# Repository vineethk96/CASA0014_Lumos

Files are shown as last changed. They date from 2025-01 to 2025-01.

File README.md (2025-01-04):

# CASA0014_Lumos

<p align="center">
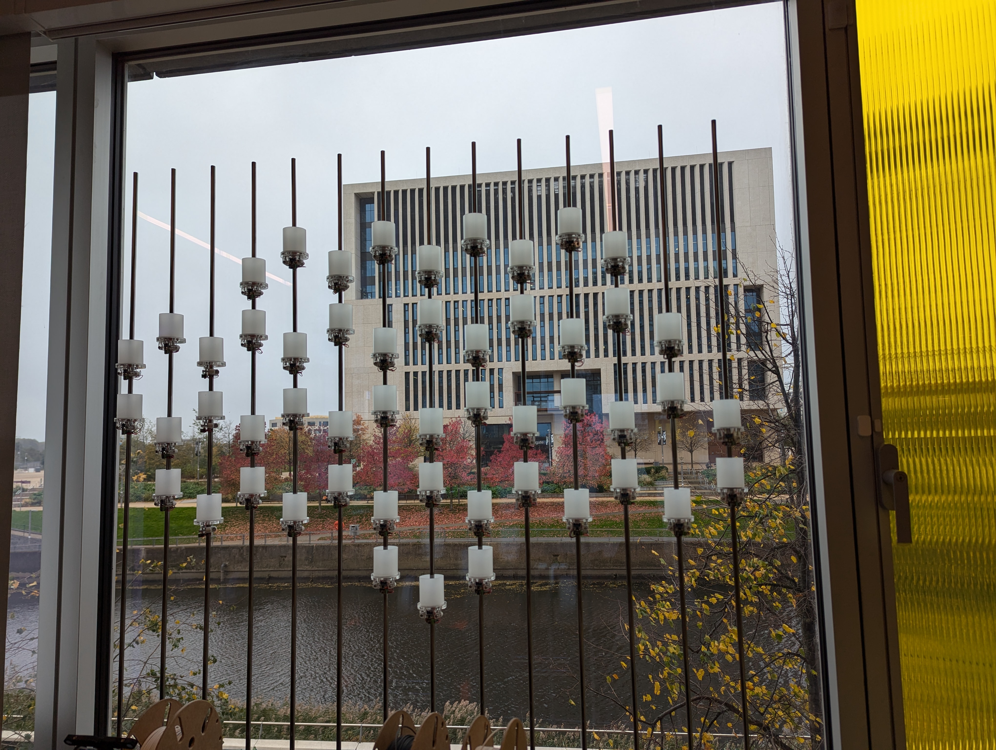
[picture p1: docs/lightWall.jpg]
    
</p>

### Description

Lumos is an User Interface that allows individuals to control individual lights on the Light Wall.

The Light Wall works by using an MQTT Server that listens to incoming messages to the Topic `mqtt.cetools.org/student/CASA0014/light/`
These messages can identify which LED Node to select by adding the corresponding number to the topic, as well as exactly which pixel to illuminate and it's color within the message body as so:

```
{
"pixelid": ledNode,
"R": red_byte,
"G": green_byte,
"B": blue_byte,
"W": white_byte
}
```

To interact with the Light Wall, Lumos uses a collection of 3 TLV493D Magnetometers to read the distance a magnet is from them to create a light value between 0 and 255. Each of the 3 magnetometers are designated Red, Green, and Blue, and the magnet itself is held within the wand.
Users can also select a specific LED Node to light up using the dial to the left of the ring.

## Features

- LED Node Selection via Dial
- Color Changeability via Ring and Wand

## Contents

- Hardware Used
  - Areas for Improvement
- Software Overview
  - Installation and Running
  - Architecture
  - Algorithms
  - Areas for Improvement
- Inspiration and Helpful Links

## Hardware

- Arduino MKR WIFI 1010 (Microcontroller)
- TLV493D (Magnetometer)
- TCA9548A (I2C Multiplexer)
- PEC11 (Rotary Encoder)
- SSD1306 (OLED Display)

### Areas for Improvement

The major area for improvement is with the TLV493D magnetometers. They are not strong enough to detect a proper magnetic disturbance outside of 3-4cm away.

## Software

### Installation and Running

This project was developed using the PlatformIO extension on Visual Studio Code. To start with users must install both items, which can be found at the below links:

- [Visual Studio Code](https://code.visualstudio.com/download)
- [PlatformIO IDE](https://platformio.org/platformio-ide)

Additionally, the following libraries must be installed:

```
	arduino-libraries/WiFiNINA@^1.8.14
	adafruit/Adafruit NeoPixel@^1.12.3
	adafruit/Adafruit GFX Library@^1.11.11
	adafruit/Adafruit SSD1306@^2.5.13
	adafruit/Adafruit BusIO@^1.16.2
	paulstoffregen/Encoder@^1.4.4
	bblanchon/ArduinoJson@^7.2.0
	knolleary/PubSubClient@^2.8
	infineon/TLV493D-Magnetic-Sensor@^1.0.4
	wifwaf/TCA9548A@^1.1.3
```

Once the above applications, extensions, and libraries have been installed, the application can be run by clicking the Arrow button at the bottom of the screen, and opening the Serial Monitor with the Plug.

#### Quick PlatformIO Info:

##### Install Libraries

Once PlatformIO is installed, an alien head should pop up on the left toolbar
PlatformIO_Logo

Click the head, and on the left bar there will be a `Quick Access` table, and under `PIO Home` there will be a `Libraries` entry.
From here, you can install all the libraries.

##### Build and Running Applications

At the bottom toolbar you will see a couple new items.

- The Checkmark will build your code.
- The Arrow will upload your code to the microcontroller
- The Plug will open the Serial Terminal

### Architecture

#### Hardware

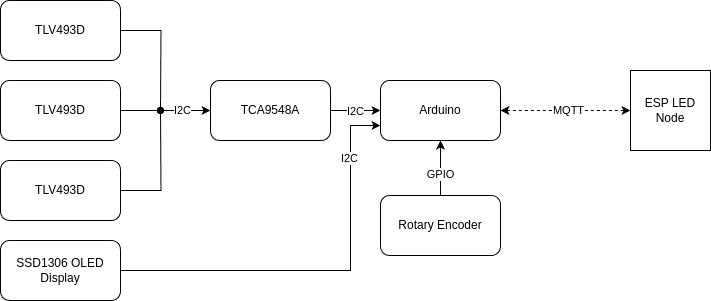
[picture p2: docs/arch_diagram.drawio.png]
Basic Circuit


#### Software

At a high-level everything is broken down by it's physical functionality. The project itself is comprised of 2 parts: the dial, and the ring. As such, the `EncoderKnob` library contains everything to communicate with the components of the ring, those being the PEC11 Rotary Encoder, and the SSD1306 OLED Display. Equally the ring is simply the readings from the 3 magnetometers, and the mapping.

### Algorithms

Two simple algorithms were build for this application. One for rotating between I2C Channels on the Mux, and the other for cleaning up the incoming readings from the magnetometers to get a more meaningful and accurate representation of the data.

#### I2C Switching

The TCA9548A multiplexer works by allowing the user access to 1 of it's 8 possible I2C channels at a single time. Therefore, when interfacing with multiple components with the same I2C Address, I designed a simple, but effective method to switch between channels, while also saving memory. This works by making a single generic magnetometer object, and using a enumerated value to iterate between the channels.

#### Input Data Cleanup

As a result of using this magnetometer for the project, the recorded strength of the magnet significantly dropped off when about 5 to 6 cm away. This paired with the speed and switching of device readings, led to very inconsistent readings which didn't make a lot of sense to what the users would percieve. To solve this, I applied a rolling average algorithm, along with a different mapping to adjust the values. The current issue with this, is since the values are so low at around 5 to 6 cm away, the color saturation really just transitions from on to off, without much of a gradient betwen them. This can be cleaned up with a magnetometer with a larger field of reading, or even more powerful magnets.

### Areas for Improvement

The primary area would be to clean up the input mappings, also selecting magnetometers with an adjustable I2C address would remove the need for the mux, and simplify the code, while providing faster readings.
Also, there was an attempt at creating a library to quickly create and send the MQTT messages, however after testing, using the MQTT message to change the whole light at once added too much extra complexity for an inconsistent output.

## Inspiration and Helpful Links

- https://www.instructables.com/OLED-I2C-DISPLAY-WITH-ARDUINO-Tutorial/
- https://www.instructables.com/Arduino-and-the-SSD1306-OLED-I2C-128x64-Display/
- https://github.com/scottbez1/smartknob/tree/master/cad
- https://www.instructables.com/Hackable-Rotary-Control-With-Built-in-Display-a-Te/
- https://www.thingiverse.com/thing:2641409

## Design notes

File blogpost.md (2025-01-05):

# Project Lumos

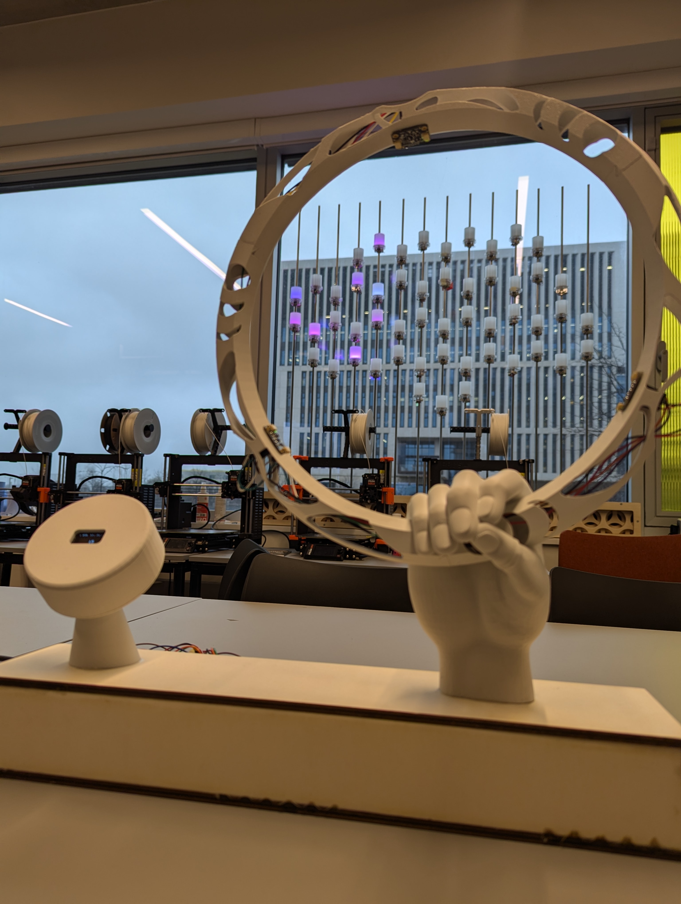
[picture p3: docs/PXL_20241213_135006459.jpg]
Lumos


In the age of connected systems, user interfaces are getting increasingly boring and digitized. Monocolor apps with color wheels have taken away from the tactile buttons and knobs of the past. This project seeks to break those patterns, and bring back the fun in interacting with smart tech.

There is a word that this project is built around. One that my professor had mentioned early in the term. We were talking about how ubiquitous systems are built, how we use various wireless technologies to interact with our environment in a way that people never notice. He said that it all works like "Magic", and that stuck.

You can't go anywhere now without experiencing the magic; from resturant pagers, to smart HVAC systems, there are invisible data streams everywhere. To most developers, we use various apps and dashboards to visualize and analyze the streams. Within our homes, we have smart assistants like Google Home or Amazon Alexa to flip lights. If we want more detailed control, we have to open the app, and go through various menus to get to the exact items we want to change. Suddenly the magic is broken. The blinding blue light from the screen, the tapping through menus, swiping through colors, suddenly the manual labor of a switch flip has spiraled out of control.

This projects begins with a simple idea, chuck out the blue screen of death. Bring back the feel of the analog, and ubiqitous-ness of smart tech. The kinda stuff that makes you go "Wow that's like magic"

Swish&Flick

Much like the magic in the Harry Potter franchise, this project seeks to bring back that joy.

## The Boy Who Lived (Introduction)

< Describe some background of the project >

## The Sorting Hat (Conceptualization)

As Mark Twain once said: "There is no such thing as an original idea". As such, I started off by looking at our professors device:

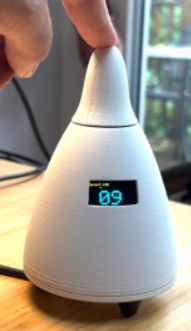
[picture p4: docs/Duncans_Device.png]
Professor Duncan's device

_Professor Duncan's implementation._

In the above image, the knob at the top selects the LED Node, and by clicking the knob, a static command is sent over MQTT to the Light wall.

I began by looking at methods to expand on the functionality of this. Add color and brightness selection to the LED Node selector. One idea was a multi-stage knob. Using multiple encoders at different levels almost like a combination lock.

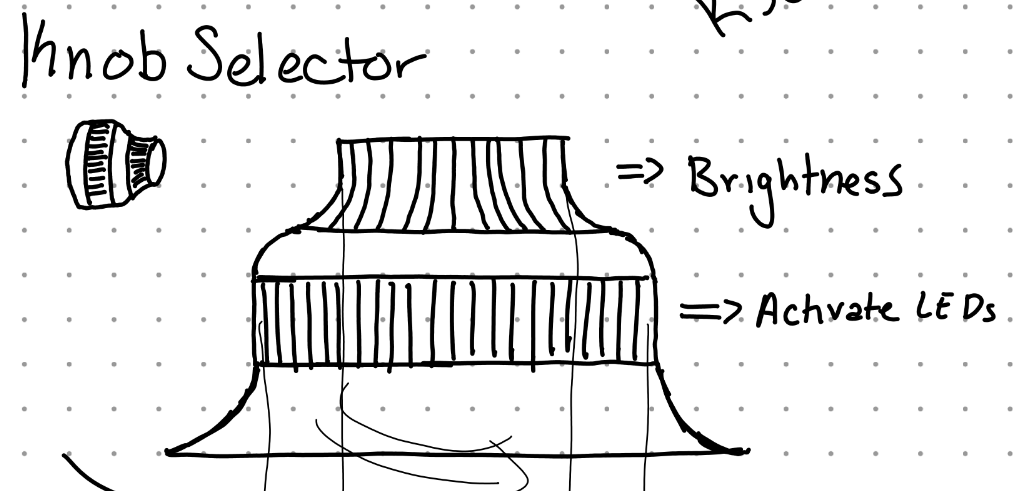
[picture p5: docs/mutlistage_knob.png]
Multistage Knob

_Multi-stage Knob_

Internally the 2 stages would be ring gears, with a unique rotary encoder as the planetary gear to adjust specific settings. However, each additional stage added an exponential increase to the physical complexity to the device. Another idea was to put a embed a touch screen to the knob face with a gradiant selector.

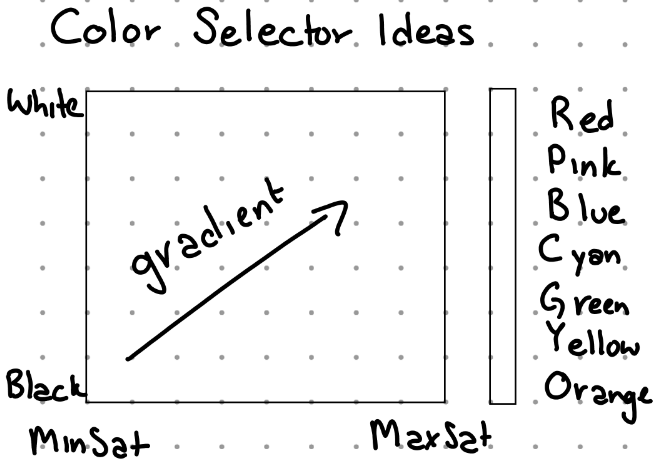
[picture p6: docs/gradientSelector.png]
Gradient Selector

_Gradient Selector_

As you might've caught on, that idea was shot down very quickly. **No touchscreens here!**

In a desperate attempt to make something unique, I began scouring the Adafruit website's sensor section looking for neat sensors I could work with. I figured finding a unique sensor would give me the niche factor I was looking for. Microphones, Strain sensors, ultrasonic, Color sensors, or gyroscopes were considered, and quickly tossed aside. Finally I came across some magnetometers, and an idea started to form.

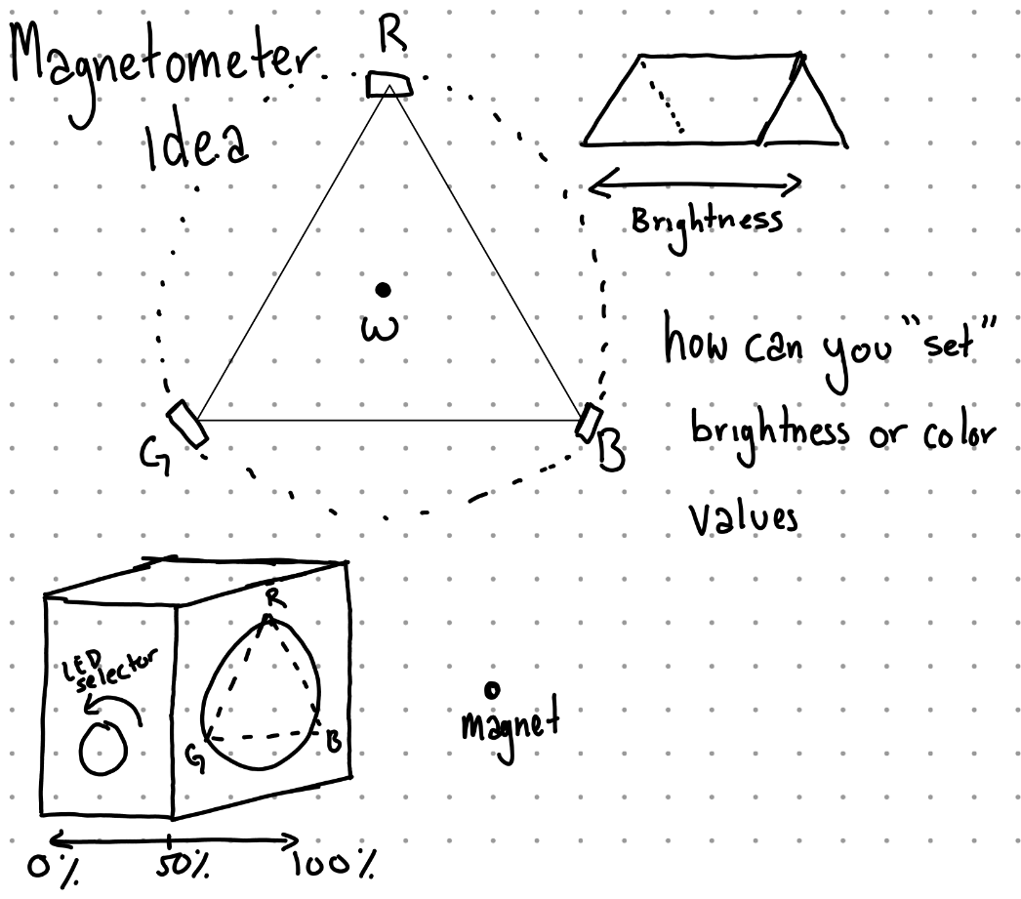
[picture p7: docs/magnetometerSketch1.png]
Magnetometer Sketches

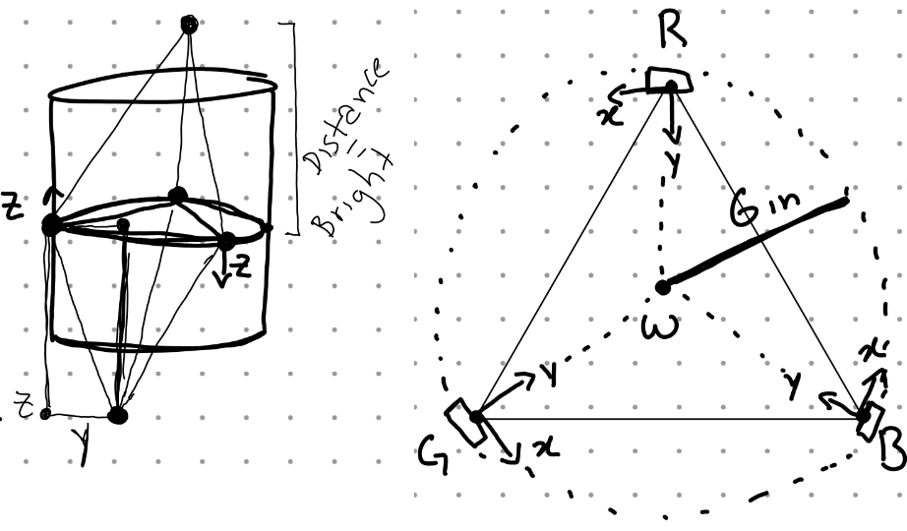
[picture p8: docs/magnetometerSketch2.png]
Magnetometer Sketches

_Magnetometer sketches and functional mapping_

By arranging 3 magnetometers in a triangle, I could wave a magnet between them, and get a whole gradient of colors. On top of that, the sensors could also measure the magnetic field in the X, Y, and Z coordinates, meaning this could be further enhanced by moving the magnet closer and further to the sensors to adjust the brightness. With the magnetometer selected, and an initial concept mapped out, I needed to figure out how all these ideas were going to come together. It wasn't enough to just change the color of a single LED Node, but I had to also select the specific node. Leaning on the knob concept from Duncan, I decided to incorporate both into a single design.

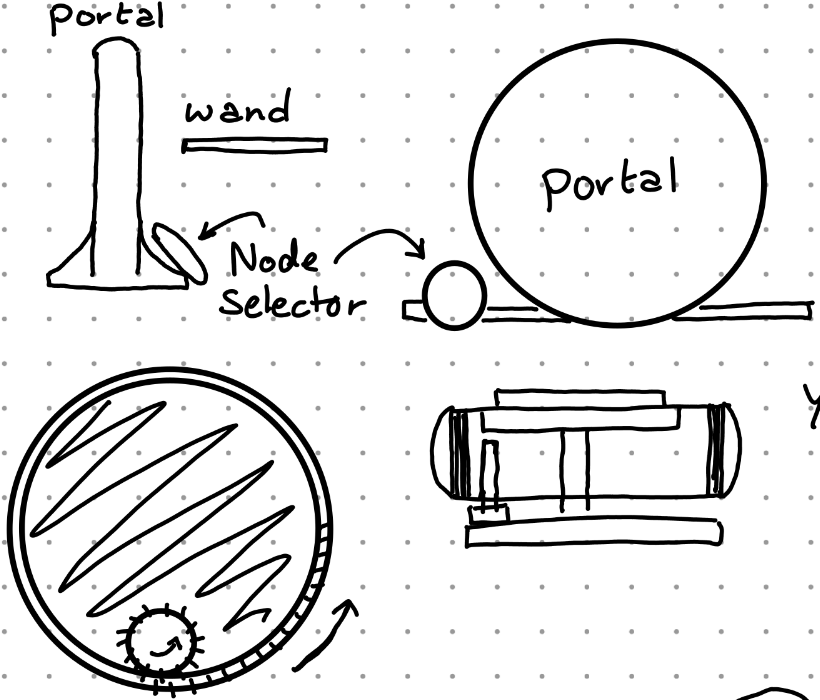
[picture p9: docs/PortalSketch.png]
Initial Portal Sketches

_Initial Project Sketches_

The final descision was to implement both. A knob which could select a LED Node, and a ring (described as the Portal) which holds the magnetometer array to adjust colors.

## Diagon Alley (Collecting Components)

< Purchasing items >
Breaking down the systems.
There are 2 systems, the Ring and the Knob

## The Journey from Platform Nine and Three-Quarters (Modeling and Assembly)

< Modeling and Assembly >

## Through the Trapdoor (Software and Algorithms)

< Software and Algo Overview >

## The Mirror of Erised (Reflections)

< Reflections >

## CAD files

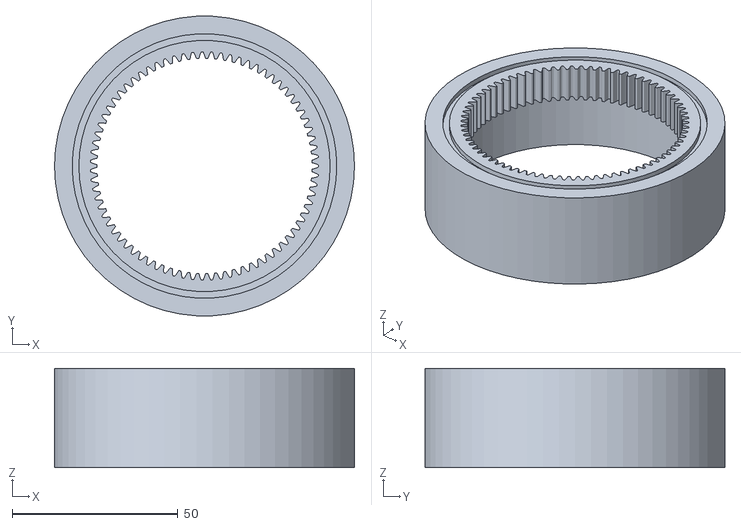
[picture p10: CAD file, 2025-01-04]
cad/dial/v1.1/ringGear.stl
90.5 x 90.4 x 30.0

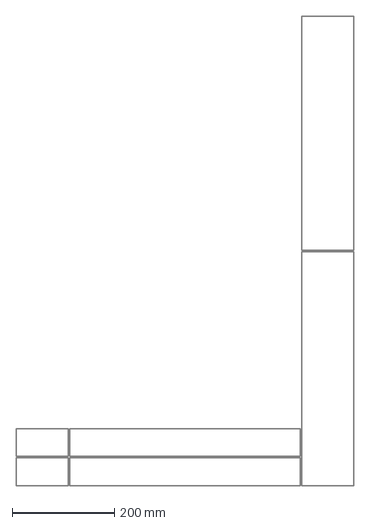
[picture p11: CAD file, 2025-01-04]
cad/portal/v1.1/box.dxf
660.4 x 917.4 mm

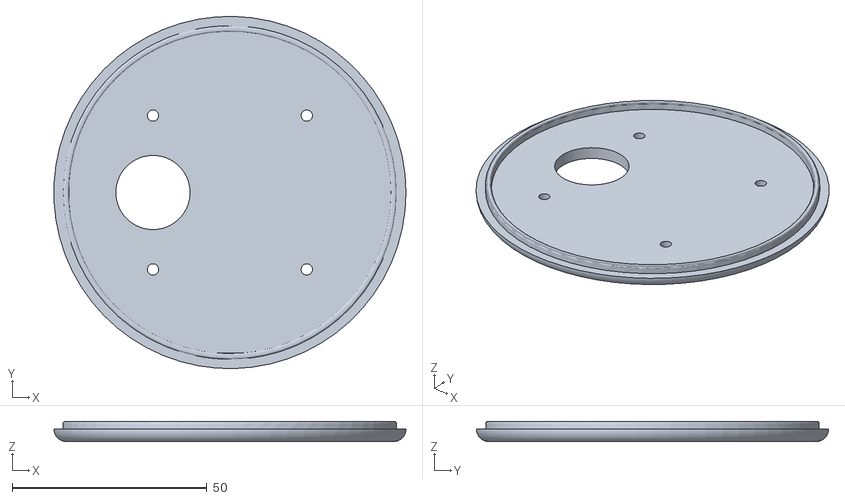
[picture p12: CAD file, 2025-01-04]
cad/dial/v1.1/basePlate.stl
90.4 x 90.5 x 5.18

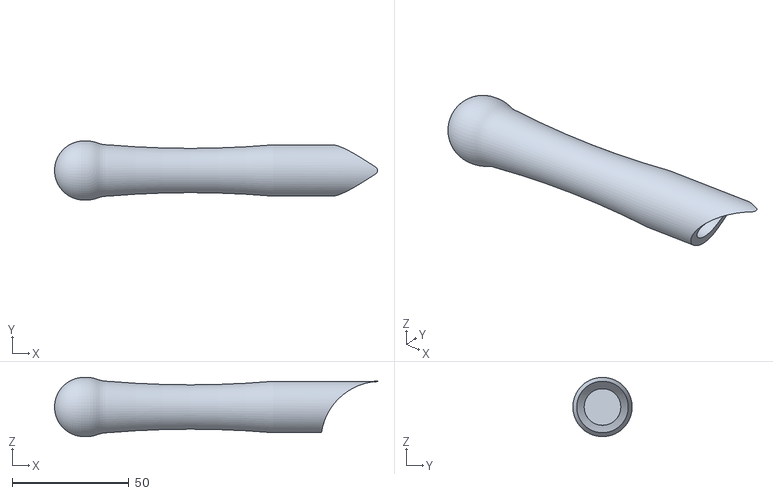
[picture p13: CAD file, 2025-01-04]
cad/portal/v1.1/wandHandle_v1.1.stl
138.3 x 25.4 x 25.4

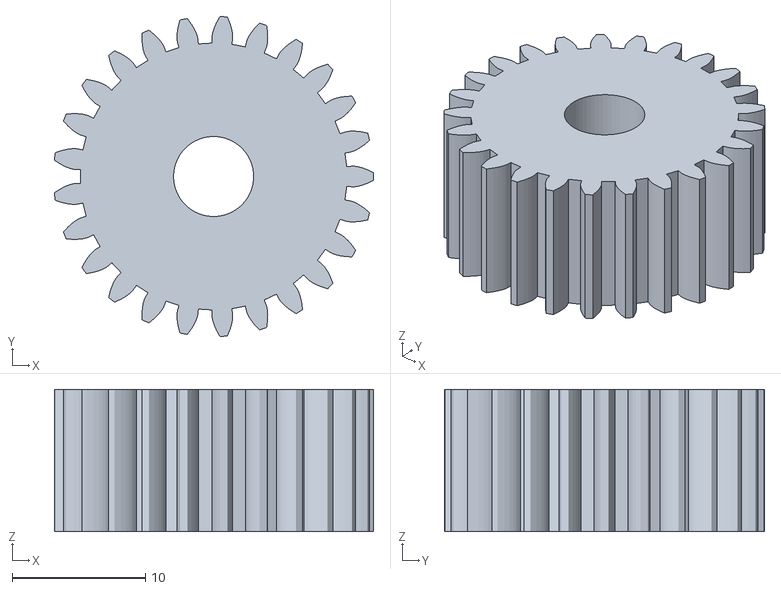
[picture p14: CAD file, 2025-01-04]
cad/dial/v1.1/rotarySpur.stl
23.9 x 24.0 x 10.7

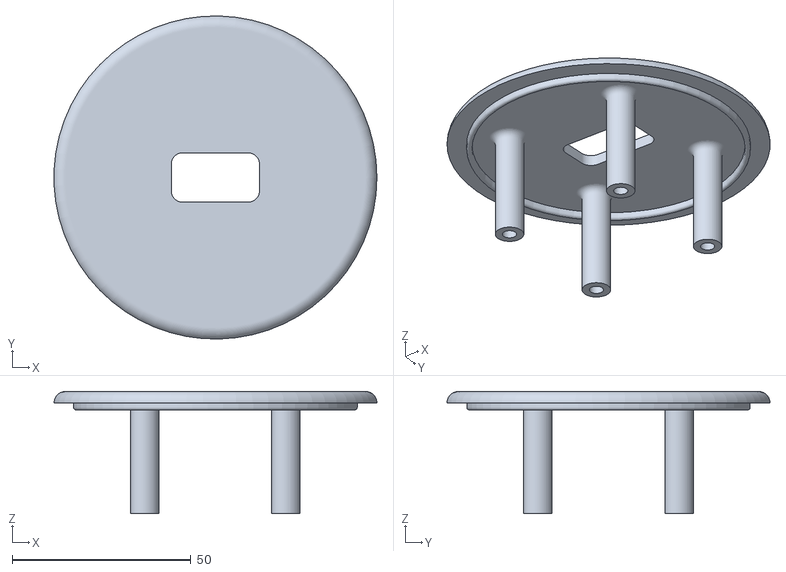
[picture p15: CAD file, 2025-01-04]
cad/portal/v1.1/topPlate_v1.1.stl
90.4 x 90.5 x 34.2

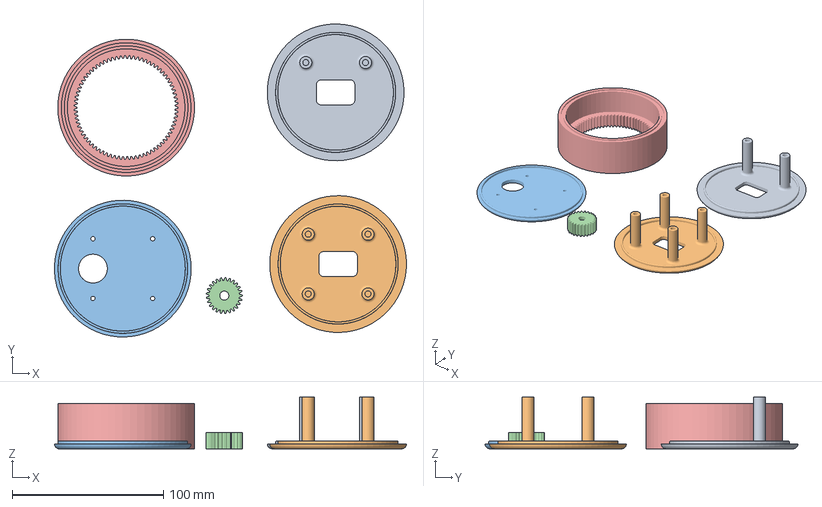
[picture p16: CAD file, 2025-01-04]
cad/dial/v1.1/topPlate_2Leg.3mf
232.8 x 207.0 x 34.2 mm
topPlate_2Leg.stl
topPlate.stl
basePlate.stl
rotarySpur.stl
ringGear.stl

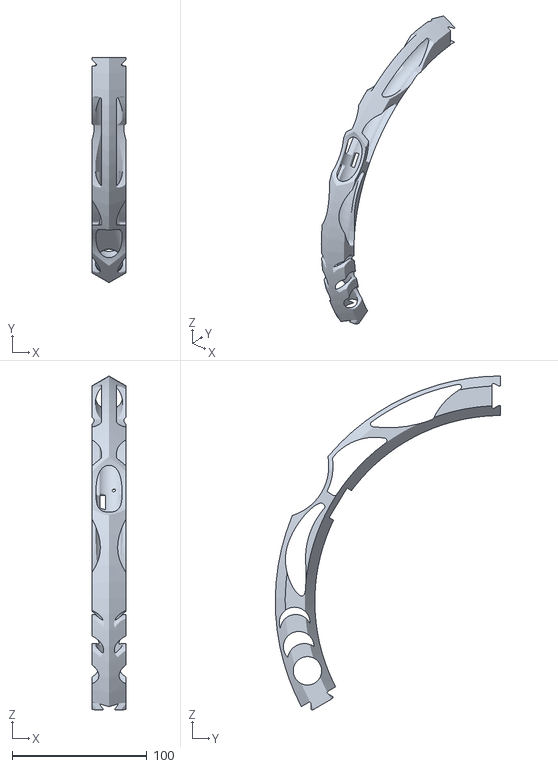
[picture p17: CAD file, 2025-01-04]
cad/portal/v1.1/thirdArc_v1.1.stl
25.4 x 167.0 x 247.5

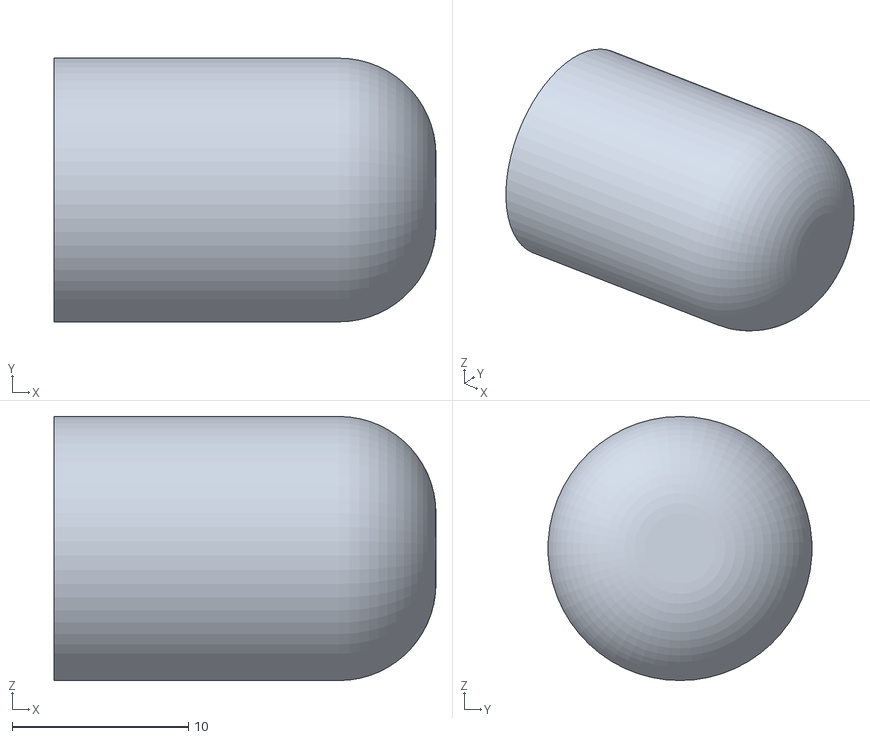
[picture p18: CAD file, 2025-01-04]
cad/portal/v1.1/wandCap_v1.1.stl
21.7 x 15.0 x 15.0

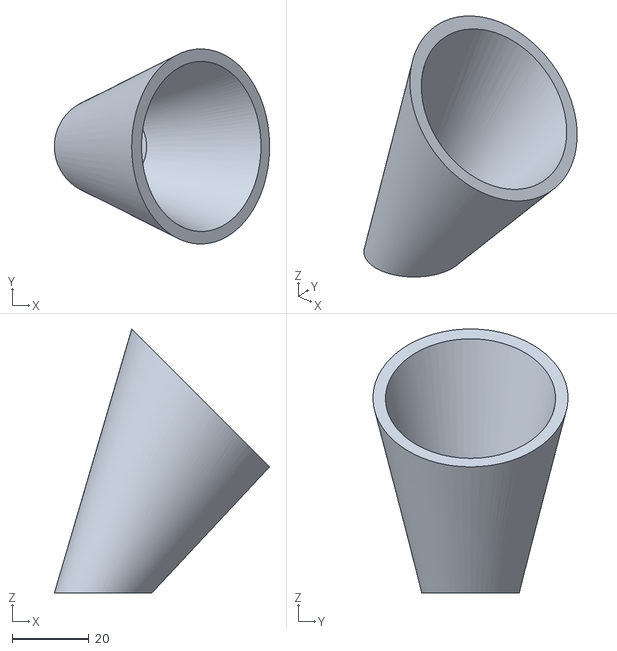
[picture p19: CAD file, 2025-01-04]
cad/portal/v1.1/mount_v1.1.stl
56.1 x 50.8 x 68.8

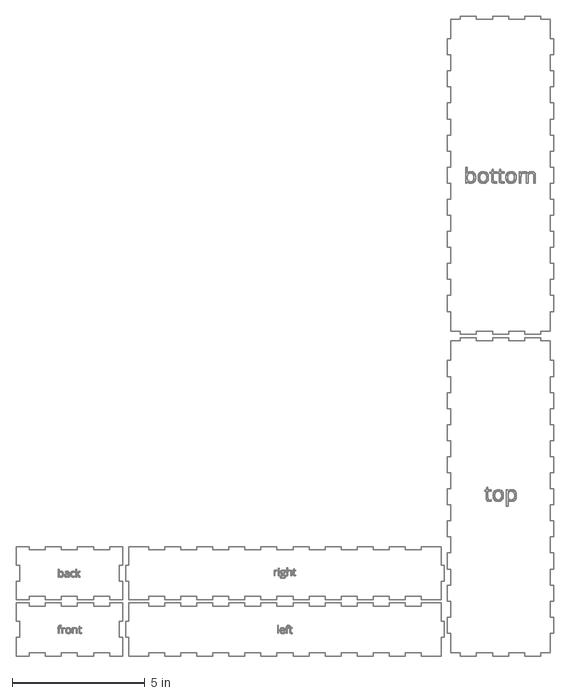
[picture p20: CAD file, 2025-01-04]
cad/portal/v1.1/podium.dxf
20.2 x 24.1 in

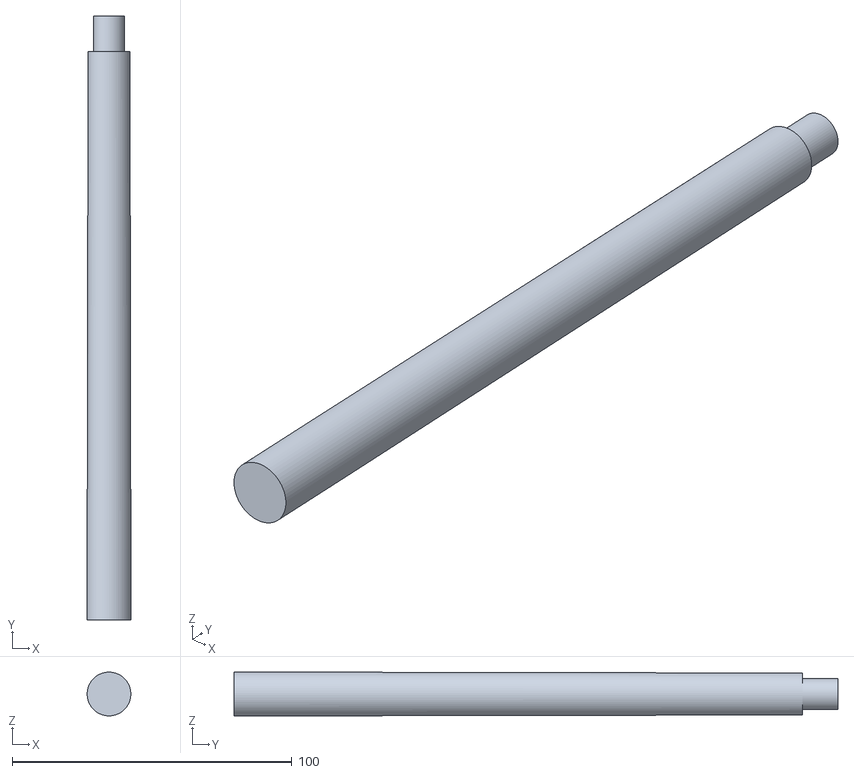
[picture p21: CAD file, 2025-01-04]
cad/portal/v1.1/wandBody_v1.1.stl
15.6 x 215.9 x 15.7

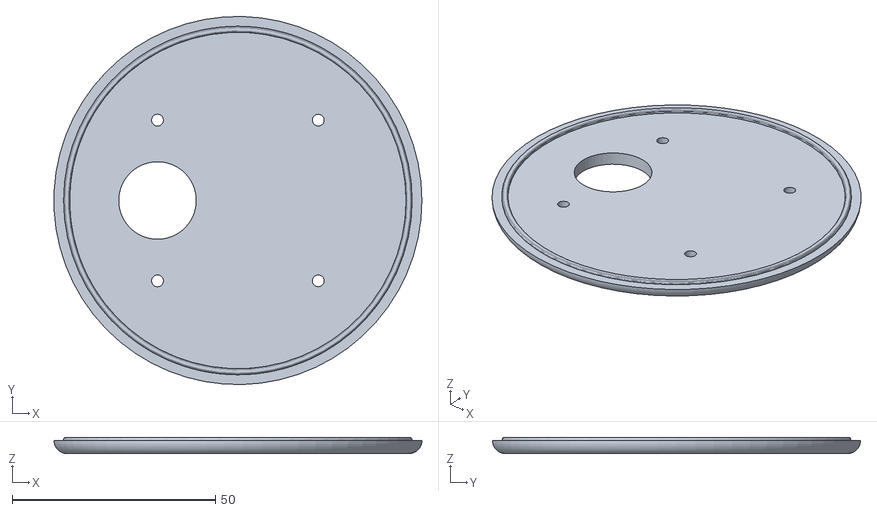
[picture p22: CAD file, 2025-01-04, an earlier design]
cad/dial/v1.0/basePlate - Part 1.stl
90.4 x 90.5 x 3.98

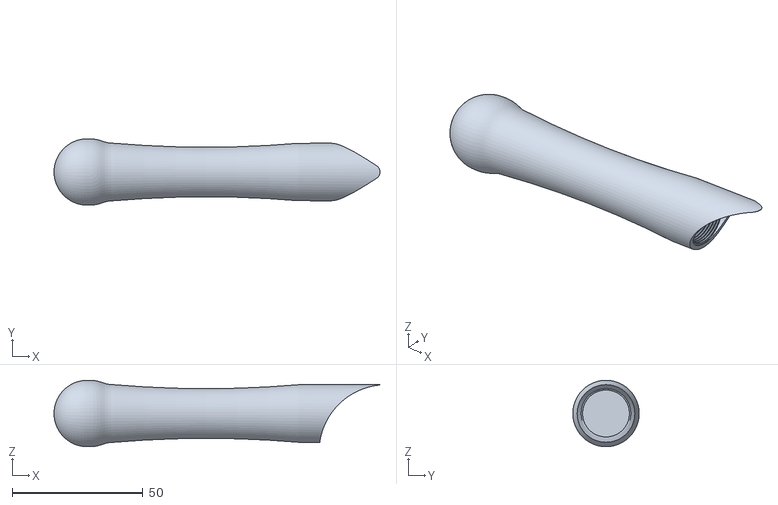
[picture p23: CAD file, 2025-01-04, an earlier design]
cad/portal/v1.0/wandHandle_v1.0.stl
124.6 x 25.4 x 25.4

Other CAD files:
cad/dial/v1.1/topPlate.stl
cad/dial/v1.0/topPlate - Part 1.3mf
cad/portal/v1.0/thirdArc_v1.0.stl
cad/dial/v1.0/ring_gear.3mf
cad/dial/v1.0/ring_gear.stl
cad/dial/v1.0/rotary_gear.stl
cad/dial/v1.0/topPlate - Part 1.stl
cad/dial/v1.1/topPlate_2Leg.stl
cad/portal/v1.0/HOLYHand_v1.0.stl
cad/portal/v1.0/wandBody_v1.0.stl
cad/portal/v1.0/wandCap_v1.0.stl

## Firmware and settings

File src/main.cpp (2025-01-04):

/**
 * @file main.cpp
 * @author Vineeth Kirandumkara (vineeth.kirandumkara.24@ucl.ac.uk)
 * @brief Lumos is a project to communicate with a wall of LED Nodes within the CE Lab.
 * @version 0.1
 * @date 2024-10-29
 *
 * @copyright Copyright (c) 2024
 *
 */

// Third Party Lib
#include <Arduino.h>
#include <WiFiNINA.h>
#include <PubSubClient.h>
#include <utility/wifi_drv.h>
#include <Adafruit_NeoPixel.h>
#include <Wire.h>
#include "string.h"

// My Lib
#include "./arduino_secrets.h"
// #include "LuminaMsg.hpp"
#include "EncoderKnob.hpp"
#include "MagTrio.hpp"

// Pins
#define ENCODER_A 7
#define ENCODER_B 6

// #define TEST_NO_WIFI // For at home testing with no MQTT

/* TODO: REMOVE GLOBALS */

#ifndef TEST_NO_WIFI
// Global Variables
const char *ssid = SECRET_SSID;
const char *pass = SECRET_PASS;
const char *mqtt_username = SECRET_MQTTUSER;
const char *mqtt_password = SECRET_MQTTPASS;
const char *mqtt_server = "mqtt.cetools.org";
const int port = 1884;
wl_status_t status = WL_IDLE_STATUS; // the Wifi radio's status

// Global Objects
WiFiServer server(80);
WiFiClient wifiClient;
#endif

char *topic;

#ifndef TEST_NO_WIFI
WiFiClient mkrClient;
PubSubClient client(mkrClient);
#endif

// LuminaMsg mqtt_msg(topic_base);
EncoderKnob ledDial(ENCODER_A, ENCODER_B, 0, Wire);
MagTrio mags(Wire);

// Function Declarations
void startWifi(void);
void reconnectMQTT(void);
void sendMQTT(char *topic, char *msg);
void lightNode(uint8_t nodeNum, uint8_t red, uint8_t green, uint8_t blue, uint8_t white);

void setup()
{
  // HARDWARE SETUP
  // Begin the Serial Comms for Debugging
  Serial.begin(9600);
  // Wait for Serial to boot up...
  while (!Serial)
    ;

  // Begin LED Dial Unit
  if (!ledDial.begin())
  {
    Serial.println("Led Dial Failed to Initialize.");
    while (1)
      ;
  }

  mags.begin();

#ifndef TEST_NO_WIFI
  // MQTT SETUP
  WiFi.setHostname("Lumina_Vineeth");
  startWifi();
  client.setServer(mqtt_server, port);
  Serial.println("setup complete");
#endif
}

void loop()
{

  static unsigned long timestamp = millis();

#ifndef TEST_NO_WIFI
  // we need to make sure the arduino is still connected to the MQTT broker
  // otherwise we will not receive any messages
  if (!client.connected())
  {
    Serial.println("Attempting to reconnect to MQTT...");
    reconnectMQTT();
  }

  // we also need to make sure we are connected to the wifi
  // otherwise it will be impossible to connect to MQTT!
  if (WiFi.status() != WL_CONNECTED)
  {
    Serial.println("Attempting to reconnect to WiFi");
    startWifi();
  }
#endif

  // Update the Magnetometer readings
  mags.update();

  // Update at the fastest speed possible
  ledDial.update();

  /**
   * Actions go here!
   *
   */

  // Every 500 ms, send a new message
  if (millis() - timestamp > 500)
  {
    lightNode(ledDial.getReading(), mags.getRed(), mags.getGreen(), mags.getBlue(), 100);
    timestamp = millis(); // Update Timestamp
  }

#ifndef TEST_NO_WIFI
  // check for messages from the broker and ensuring that any outgoing messages are sent.
  client.loop();
#endif
}

void startWifi()
{
#ifndef TEST_NO_WIFI
  // check for the WiFi module:
  if (WiFi.status() == WL_NO_MODULE)
  {
    Serial.println("Communication with WiFi module failed!");
    // don't continue
    while (true)
      ;
  }
  String fv = WiFi.firmwareVersion();
  if (fv < WIFI_FIRMWARE_LATEST_VERSION)
  {
    Serial.println("Please upgrade the firmware");
  }

  // Function for connecting to a WiFi network
  // is looking for UCL_IoT and a back up network (usually a home one!)
  int n = WiFi.scanNetworks();
  Serial.println("Scan done");
  if (n == 0)
  {
    Serial.println("no networks found");
  }
  else
  {
    Serial.print(n);
    Serial.println(" networks found");
    // loop through all the networks and if you find UCL_IoT or the backup - ssid1
    // then connect to wifi
    Serial.print("Trying to connect to: ");
    Serial.println(ssid);
    for (int i = 0; i < n; ++i)
    {
      String availablessid = WiFi.SSID(i);
      // Primary network
      if (availablessid.equals(ssid))
      {
        Serial.print("Connecting to ");
        Serial.println(ssid);
        WiFi.begin(ssid, pass);
        while (WiFi.status() != WL_CONNECTED)
        {
          delay(600);
          Serial.print(".");
        }
        if (WiFi.status() == WL_CONNECTED)
        {
          Serial.println("Connected to " + String(ssid));
          break; // Exit the loop if connected
        }
        else
        {
          Serial.println("Failed to connect to " + String(ssid));
        }
      }
      else
      {
        Serial.print(availablessid);
        Serial.println(" - this network is not in my list");
      }
    }
  }

  Serial.println("");
  Serial.println("WiFi connected");
  Serial.print("IP address: ");
  Serial.println(WiFi.localIP());

#endif
}

void reconnectMQTT(void)
{
#ifndef TEST_NO_WIFI
  if (WiFi.status() != WL_CONNECTED)
  {
    startWifi();
  }
  else
  {
    // Serial.println(WiFi.localIP());
  }

  // Loop until we're reconnected
  while (!client.connected())
  { // while not (!) connected....
    Serial.print("Attempting MQTT connection...");
    // Create a random client ID
    String clientId = "LuminaSelector";
    clientId += String(random(0xffff), HEX);

    // Attempt to connect
    if (client.connect(clientId.c_str(), mqtt_username, mqtt_password))
    {
      Serial.println("connected");
      // ... and subscribe to messages on broker
    }
    else
    {
      Serial.print("failed, rc=");
      Serial.print(client.state());
      Serial.println(" try again in 5 seconds");
      // Wait 5 seconds before retrying
      delay(5000);
    }
  }
#endif
}

void sendMQTT(char *topic, char *msg)
{
#ifndef TEST_NO_WIFI

  Serial.println("SENDING MSG...");
  Serial.print("Topic: ");
  Serial.println(topic);
  Serial.print("Message: ");
  Serial.println(msg);

  if (client.publish(topic, msg))
  {
    Serial.println("Message published");
  }
  else
  {
    Serial.println("Failed to publish message");
  }
#endif
}

void lightNode(uint8_t nodeNum, uint8_t red, uint8_t green, uint8_t blue, uint8_t white)
{
  // Setup the Topic
  char mqttTopic[35];
  sprintf(mqttTopic, "student/CASA0014/light/%d/pixel/", nodeNum);

  // Send messages to each pixel
  for (uint8_t i = 0; i < 12; i++)
  {
    char mqttMsg[60];
    sprintf(mqttMsg, "{\"pixelid\": %d, \"R\": %d, \"G\": %d, \"B\": %d, \"W\": %d}", i, red, green, blue, white);
    sendMQTT(mqttTopic, mqttMsg);
  }
}

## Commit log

2024-10-28 feat: first commit, just created the platformio project for the maker1010 board.
2024-11-07 feat: proof of concept allows for the rotary encoder, led strip, and oled screen all works together. Next steps are to clean up the code, and organize the functionality.
    [basePlate - Part 1.stl, basePlate.stl, ringGear.stl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]
2024-11-13 feat: updating the cad models
    [HOLEY Hand_v1.0.stl, basePlate - Part 1.stl, basePlate.stl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]
2024-11-27 chore: cad file iterations
    [HOLYHand_v1.0.stl, box.dxf, mount_v1.1.stl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]
2024-11-27 chore: updated gitignore to include print files for cad
2024-11-29 feat: massive commit, lumina msg and encoder libs are done. Previous CAD models have also been added in this commit
    [wandBody_v1.1.stl, wandCap_v1.1.stl, wandHandle_v1.1.stl]
2024-11-30 feat: magnetometer library created, testing tbd
    [wandCap_v1.1.stl]
2024-12-01 feat: modified the mapping algo to allow for a rolling average for more stable color switching. Current issue is hardware based, where the Magnetometers are basically useless when magnet is over 2 in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
    [main.cpp]
2024-12-02 bug: magnetometer sometimes outputs negative values, so I added an absolute value around the reading
    [main.cpp]
